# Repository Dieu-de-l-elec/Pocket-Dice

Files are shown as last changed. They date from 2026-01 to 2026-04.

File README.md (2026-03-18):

# Pocket Dice
It's a dice, barely bigger than a coin cell (CR2016), based upon the ATtiny1616, with 7 orange 0603 LEDs . With the press duration being recorded, it should display a near truly random generated number, unlike pseudo random number generator algorithms.

This pocket-sized dice will be my everyday companions for tabletop games or any 6D dice requiring game.

<br><br>
<p align="center">
  RENDER 1 Banner
  PCB Banner
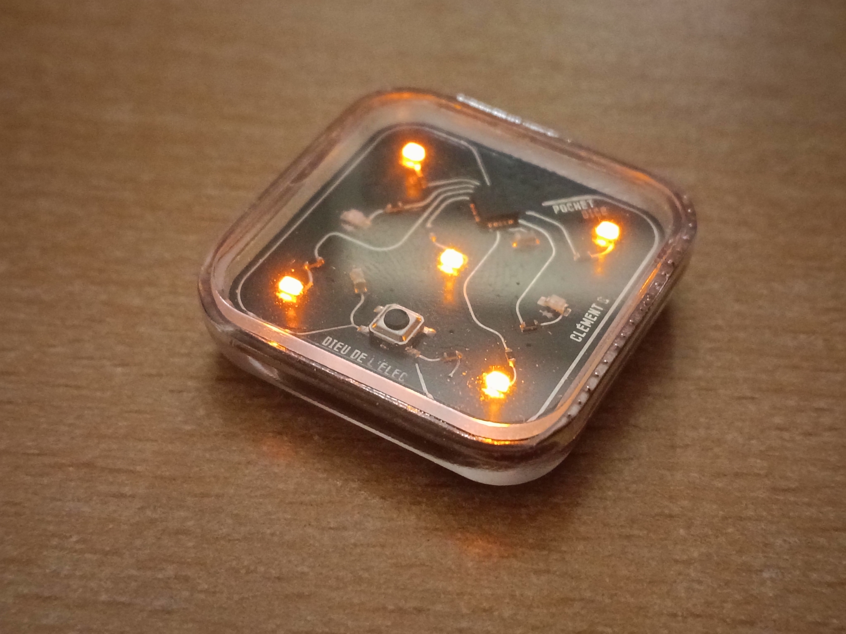
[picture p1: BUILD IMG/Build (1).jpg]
Build Image
  
</p>
<br><br>

# Key features:
- 7x 0603 LEDs (orange LEDs)
- extremely **low power consumption** (2mA average while displaying) ⇒ long battery life (CR2016), but dimmer LEDs... yet still visible enough indoor
- **Attiny1616** MCU: 16Kb Flash, Power Down sleep, extraordinarily low current consumption (VDD = 3V: 300µA running @1MHz, and 100nA in PWR down mode)
- based on **Xoshiro128+** TRNG algorithm
- button **press duration recorded** ⇒ entropy source for TRNG (along with `micros()` and analog noise on floating pin)
- Sleek design: 7mm thick, 30mm by 30mm
- 3d printed enclosure: I used JLC3DP 3D printing service, with Nylon PA12 (MJF) and 8001 transparent resin (SLA), to get a premium case, but it works too with an FDM printer.
- 1mm acrylic sheet on top that can be pressed on the lower half (a bit of flex) to press the button underneath
- MCU programmable via **UPDI**

A demo can be found here:
https://youtu.be/6FqC9Gx21-w

# Sofware:
Arduino code using SpenceKonde **MegaTinyCore** and **Xoshiro128+** TRNG algorithm.

Pressing and holding the button rolls the dice, and once released, settle down to the randomly generated number after another 3 rolls slowing down, to add a bit of animation. The dice outcome stays displayed for another 4 seconds, and then the dice goes into Power Down mode. If we want the previous outcome to be displayed again, the button can be shortly pressed, which will make the dice display the previous outcome with a blinking animation, to ensure it can't be misinterpreted as another roll.

# PCB design:
2 Layer PCB designed in EASYEDA (Pro edition). 26 by 26mm square, panelized in a 3 by 3 panel. 0.8mm board thickness

# Schematic:
SCHEMATIC

# PCB Layout:

PCB Top Layer
PCB PANEL Layout
PCB PANEL back Layout
PCB PANEL 2D
PCB PANEL 2D back

PCB 3 back 3d

# CAD and Renders:

PCB 3d render 1
PCB 3d render 2
PCB 3d render 3

RENDER 1
RENDER 2
RENDER 3
RENDER 4
RENDER 6
RENDER 5

# Build Images:

The top acrylic plate can be glued to the case with a few small drops of cyanoacrylate on the side. It would only be glued to the case along the upper edge, and on the upper half of the sides, to let the plate flex when pressed.

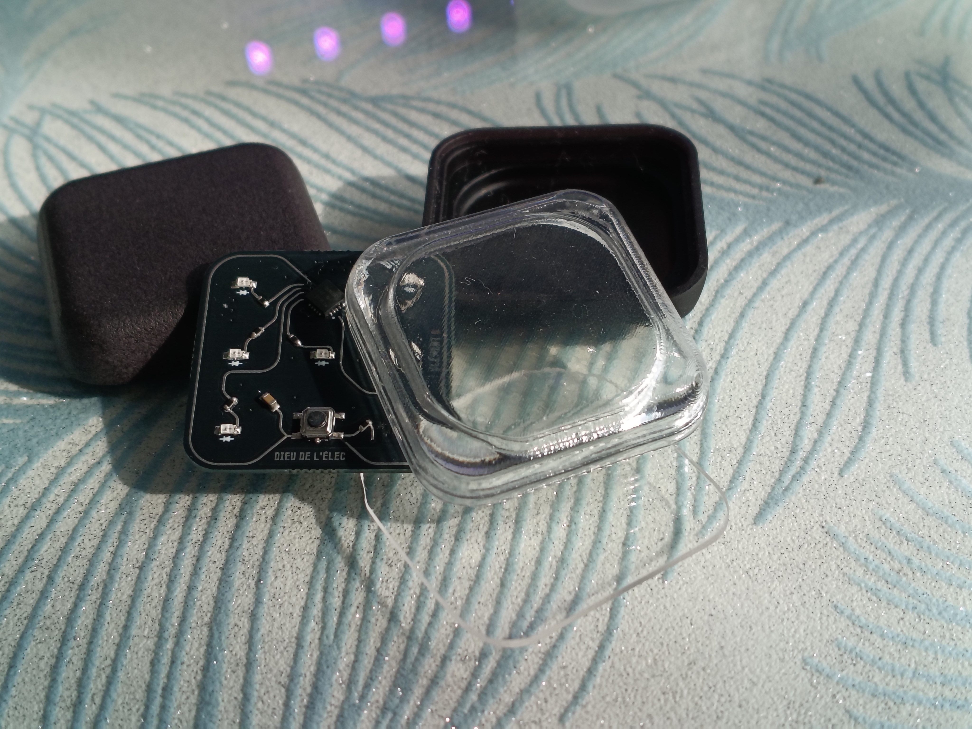
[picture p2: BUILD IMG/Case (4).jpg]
Case dissasembled dice

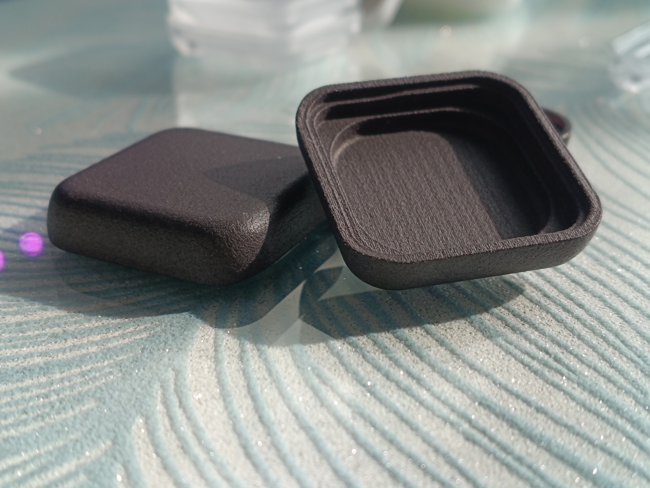
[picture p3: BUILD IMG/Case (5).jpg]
Nylon PA12 MJF case


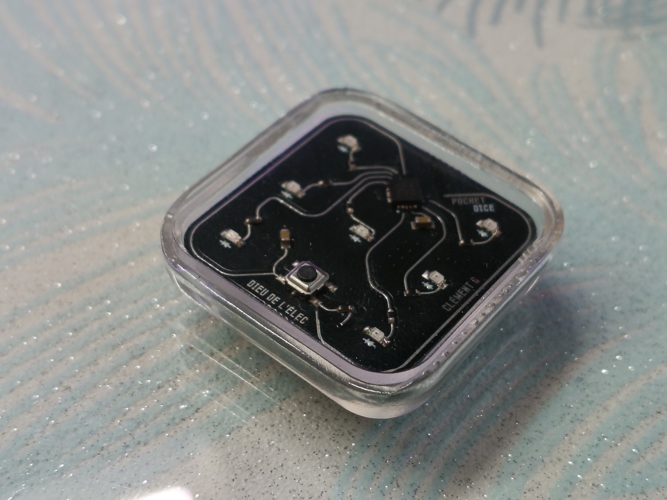
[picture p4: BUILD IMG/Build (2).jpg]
Build Image 2

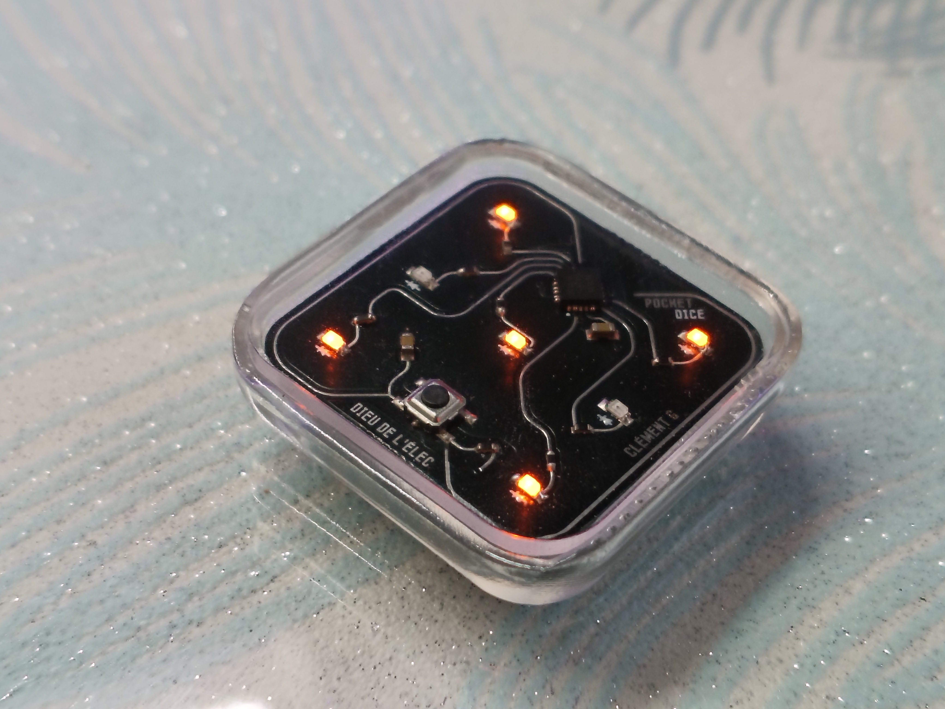
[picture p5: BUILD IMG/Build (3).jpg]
Build Image 3

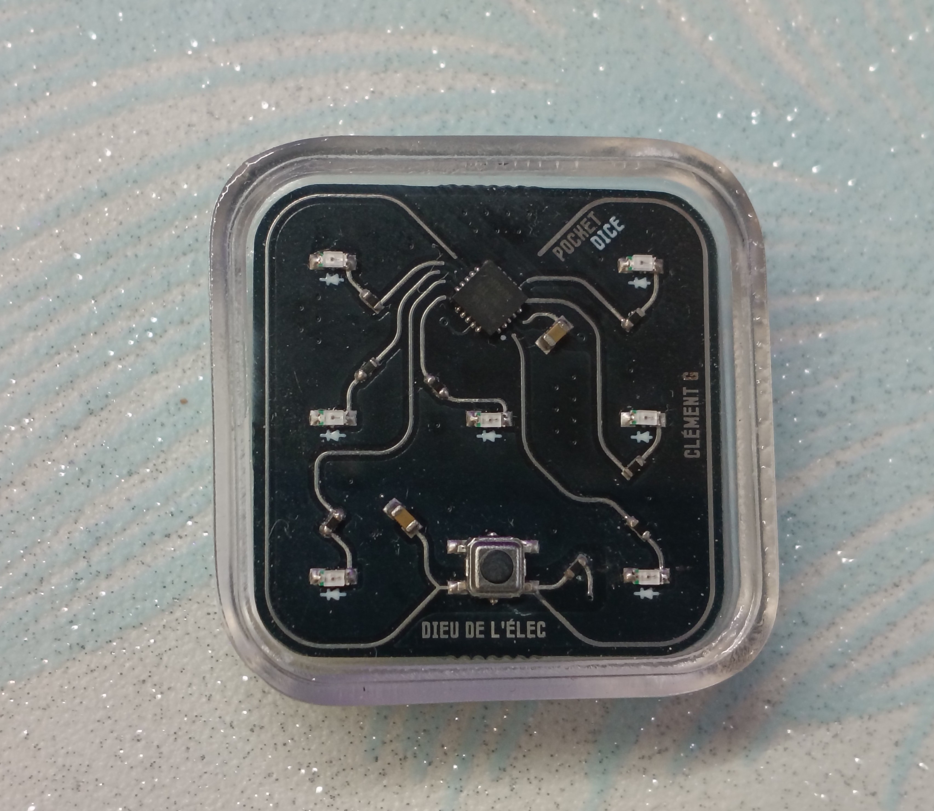
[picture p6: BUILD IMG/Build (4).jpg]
Build Image 4

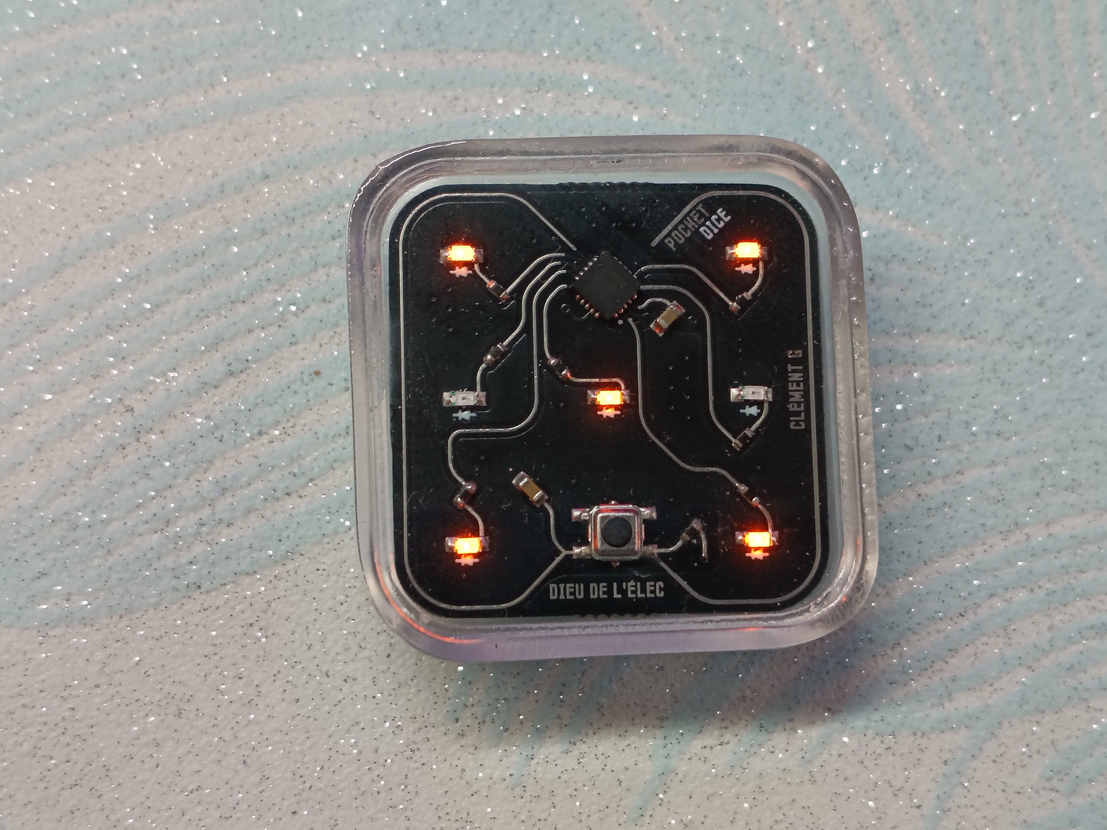
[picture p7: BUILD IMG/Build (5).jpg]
Build Image 5

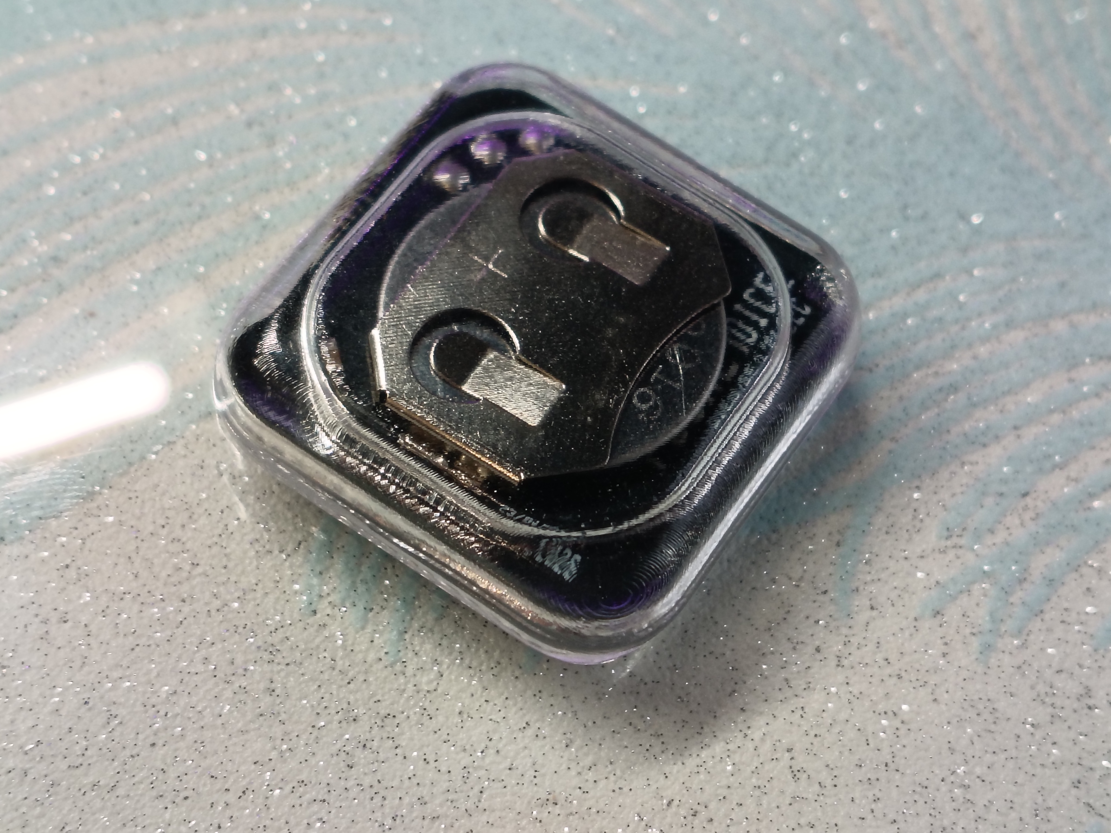
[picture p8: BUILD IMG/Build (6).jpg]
Build Image 6

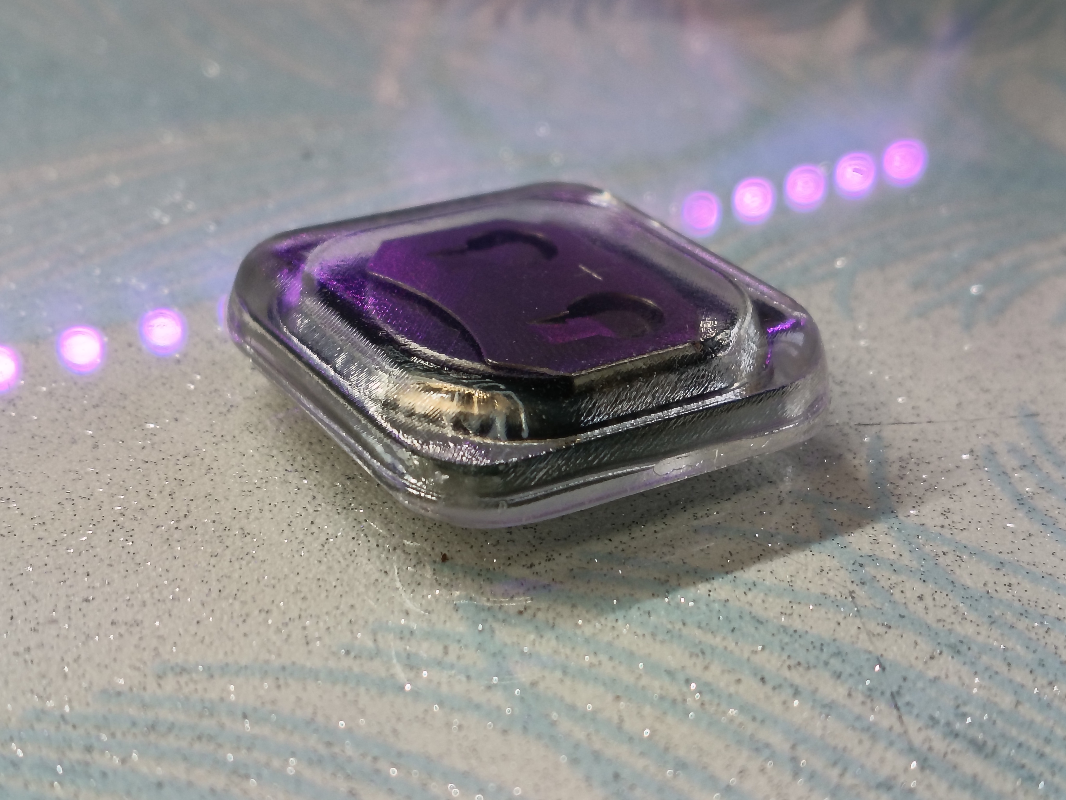
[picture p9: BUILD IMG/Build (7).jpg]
Build Image 7

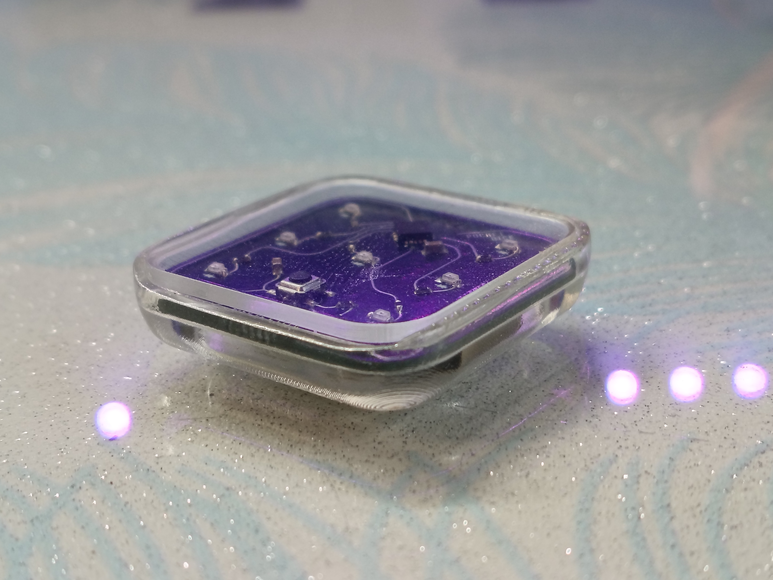
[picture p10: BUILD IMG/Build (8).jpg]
Build Image 8


Build Image 1

# BOM:

Qty	| Part	| Value | link
--- | --- | --- | ---
1 | ATtiny1616-MNR | | https://www.lcsc.com/product-detail/C507118.html
1 | CR2016 Cell SMD metal holder | | https://www.lcsc.com/product-detail/C2979176.html
1 | MLCC 0805 | 10µF | https://www.lcsc.com/product-detail/C1713.html
1 | Tactile Switch TS-1075S-A1B2-D4 | | https://www.lcsc.com/product-detail/C492872.html
2 | MLCC 0603 | 100nF | https://www.lcsc.com/product-detail/C66501.html
1 | Resistor 0402| 200k | https://www.lcsc.com/product-detail/C2906866.html
7 | Resistor 0402| 1k | https://www.lcsc.com/product-detail/C2906864.html
7 | Orange LED 0603 XL-1608UOC-06 | Vf=2.3V | https://www.lcsc.com/product-detail/C965800.html
1	| Custom PCB | | I used JLCPCB services https://jlcpcb.com
--- |  |  | 
1 | 1mm thin transparent acrylic sheet | |	I used Snijlab laser cutting services https://snijlab.nl/en
1 | 3D printed case | MJF - PA12S-HP Nylon or SLA - 8001 transparent resin (oil sprayed) | 	I used JLC3DP3D printing services https://jlc3dp.com/3d-printing-quote
1 | CR2016 Coin Cell | | Physical store

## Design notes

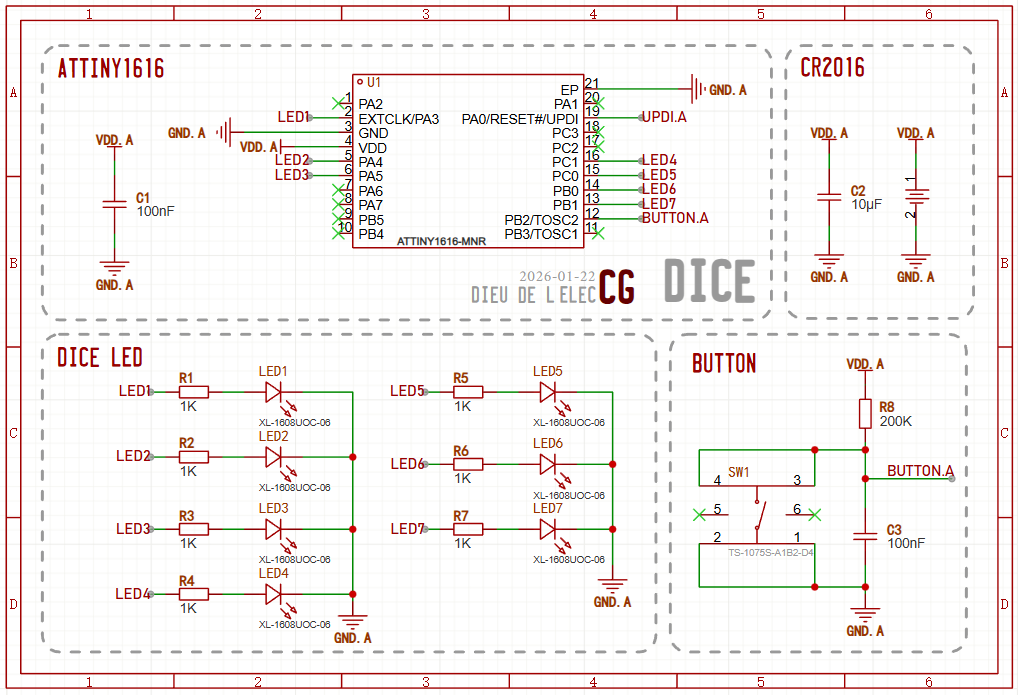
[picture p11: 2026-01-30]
assets/Schematic Dice.png

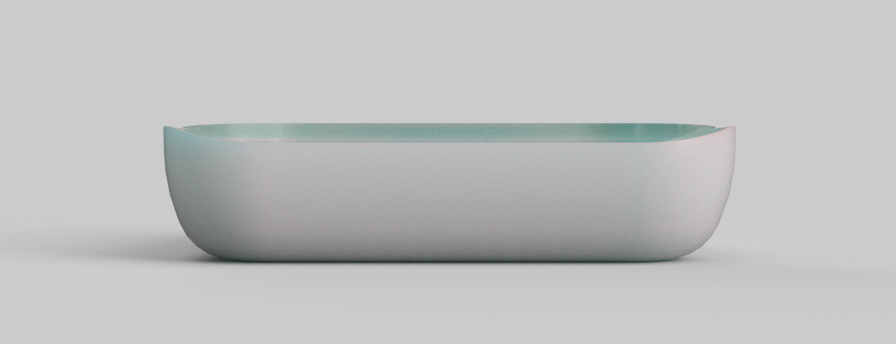
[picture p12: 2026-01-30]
assets/RENDER 3.png

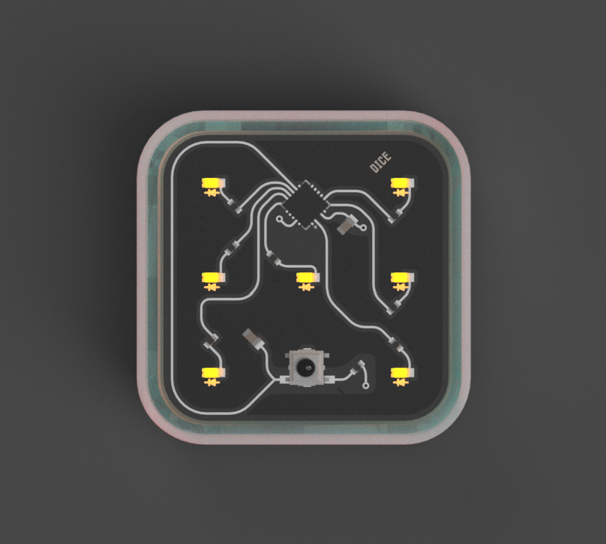
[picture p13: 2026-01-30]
assets/RENDER 2.png

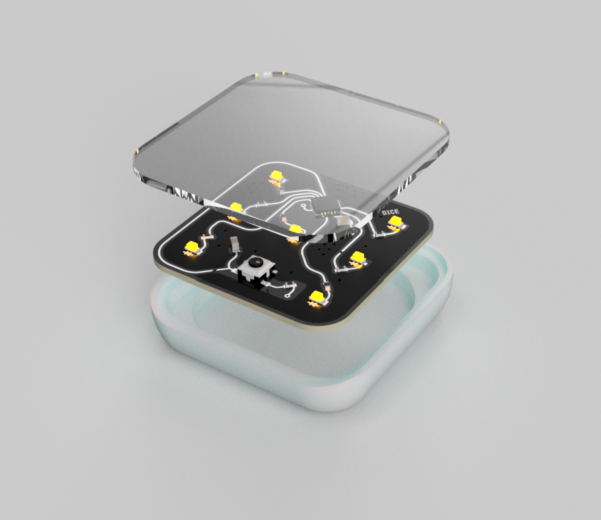
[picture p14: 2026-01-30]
assets/RENDER 5.png

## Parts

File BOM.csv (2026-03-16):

Qty | Part | Value | LCSC Part Number | price jan. 2026 (/MOQ) | Link
1 | ATTINY1616-MNR | - | C507118 | $0.911 (/1) | https://www.lcsc.com/product-detail/C507118.html
1 | metal CR2016 Cell holder | - | C2979176 | $0.76 (/5) | https://www.lcsc.com/product-detail/C2979176.html
1 | MLCC 0805 | 10µF | C1713 | $0.26 (/20) | https://www.lcsc.com/product-detail/C1713.html
1 | Tactile Switch TS-1075S-A1B2-D4 | - | C492872 | $0.6 (/10) | https://www.lcsc.com/product-detail/C492872.html
2 | MLCC 0603 | 100nF | C66501 | $0.35(/100) | https://www.lcsc.com/product-detail/C66501.html
1 | SMD resistor 0402 | 200k | C2906866 | $0.05 (/100) | https://www.lcsc.com/product-detail/C2906866.html
7 | SMD resistor 0402 | 1k | C2906864 | $0.05 (/100) | https://www.lcsc.com/product-detail/C2906864.html
7 | Orange LED XL-1608UOC-06 0603 | Vf=2.3V | C965800 | $0.69 (/100) | https://www.lcsc.com/product-detail/C965800.html
1 | Custom PCB |  |  | $4 | I used JLCPCB services https://jlcpcb.com
 | 1mm thin transparent acrylic sheet |  |  |  | I used Snijlab laser cutting services https://snijlab.nl/en
 | 3d printed case |  |  |  | I used JLC3DP 3D printing services https://jlc3dp.com/3d-printing-quote
 | CR2016 Coin cell |  |  |  | Physical Store

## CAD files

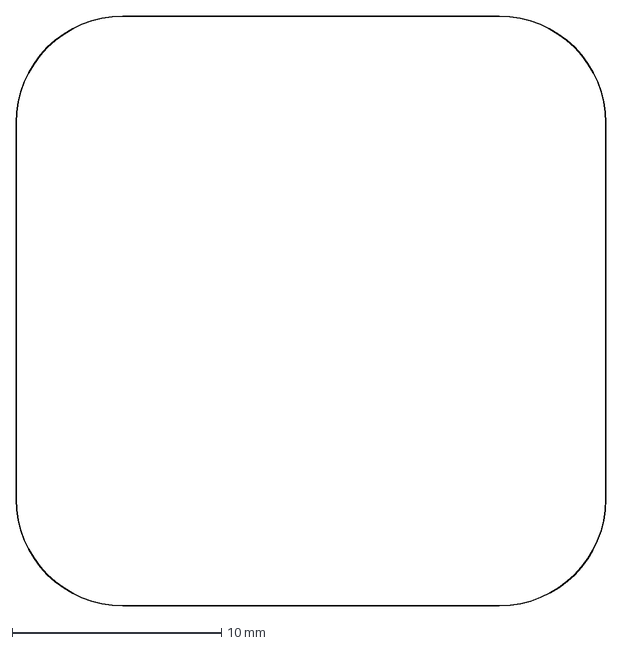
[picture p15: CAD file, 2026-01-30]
CAD/acrylic sheet DXF cutout.dxf
28.2 x 28.2 mm

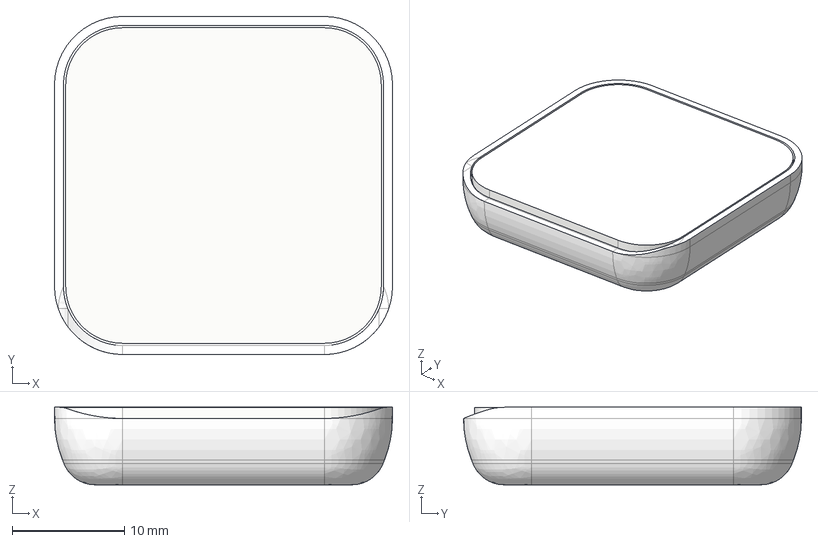
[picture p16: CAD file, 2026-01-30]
CAD/Pocket Dice CAD 3D printed Parts and top acrylic sheet.step
30.2 x 30.2 x 6.93 mm

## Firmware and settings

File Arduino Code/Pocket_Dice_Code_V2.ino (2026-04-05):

/* This is the current code (V2) for the Pocket Dice
 * Dieu de l'Elec - C.G.
 * 03.03.2026
 */ 

#include <avr/sleep.h>
#include <avr/interrupt.h>

#define BUTTON PIN_PB2

unsigned long timeCapture = 0;
volatile unsigned long timeIntCapture = 0;

byte prevDice = 0;
byte outcome = 1;
byte randomOutcome = 1;

//int counterInt = 0; // no longer needed
volatile unsigned long counterIntTime = 0;

// bool stateBtn = false; // no longer needed
volatile bool intAttribute = 1;       // interrupt attribute : 0 => button released (roll), 1 => button pressed (wake up)
// useful to know wether the intterupt means 'button pressed' or 'button released'

uint8_t LEDPins [7] {PIN_PA3, PIN_PA4, PIN_PA5, PIN_PC1, PIN_PB1, PIN_PB0, PIN_PC0};
uint8_t floatingPins [9] {PIN_PA2, PIN_PA6, PIN_PA7, PIN_PB5, PIN_PB4, PIN_PA1, PIN_PC3, PIN_PC2, PIN_PB3};
bool stateLED [7] {0, 0, 0, 0, 0, 0, 0};

void setup() {
  pinMode(BUTTON, INPUT);

  for (int p = 0; p <= 6; p++) {
    pinMode (LEDPins[p], OUTPUT);
  }

  sei();
  PORTB.PIN2CTRL = PORT_ISC_RISING_gc;
  set_sleep_mode(SLEEP_MODE_PWR_DOWN);
  timeCapture = millis();
}

void loop() {
  PORTB.PIN2CTRL = PORT_ISC_RISING_gc;

  if (intAttribute == 1) {             //                   // MCU woke up, but the button is still pressed
    randomOutcome = random(1, 7);      //                   // generate a dice outcome (rolling the dice)
    while (outcome == randomOutcome) { //                   // generate another one if it's the same outcome (just like a real dice that keeps rolling)
      randomOutcome = random(1, 7);    //
    }                                  //
    outcome = randomOutcome;           // just randomly rolling the dice for fun while the button hasn't been released
    displayDice(outcome);              //
    refreshDisplay (120);              //

    if (digitalRead (BUTTON) == 0) {
      counterIntTime = 0;
    }

    if ((millis () - counterIntTime >= 500) & (counterIntTime != 0)) {
      intAttribute = 0;
    }

  }
  if (intAttribute == 0) {                                   // if interrupt has been flagged (button released)
    PORTB.PIN2CTRL = PORT_ISC_INTDISABLE_gc;                 // disabling interrupts so it don't disturb

    unsigned long bufferTimeCapture = timeIntCapture;
    unsigned long duration = millis () - bufferTimeCapture; //bufferTimeCapture - timeCapture;
    //timeCapture = timeIntCapture;
    if (duration <= 800) {             // if short press => display previous outcome
      displayPrev();
      MCUSleep();
      return;
    }
    else {
      prevDice = generateOutcome(duration, micros());
      
      randomOutcome = random(1, 7);      //                   // generate a dice outcome (rolling the dice)
      while (outcome == randomOutcome) { //                   // generate another one if it's the same outcome (just like a real dice that keeps rolling)
        randomOutcome = random(1, 7);    //         Just dummy rolls to look more like a dice, slowing down
      }                                  //
      outcome = randomOutcome;           // just randomly rolling the dice for fun while the button hasn't been released
      displayDice(outcome);              //
      refreshDisplay (260);              //

      randomOutcome = random(1, 7);      //                   // generate a dice outcome (rolling the dice)
      while (outcome == randomOutcome) { //                   // generate another one if it's the same outcome (just like a real dice that keeps rolling)
        randomOutcome = random(1, 7);    //
      }                                  //
      outcome = randomOutcome;           // just randomly rolling the dice for fun while the button hasn't been released
      displayDice(outcome);              //
      refreshDisplay (400);              //         Just dummy rolls to look more like a dice, slowing down

      displayDiceOutcome(prevDice);
      MCUSleep();
      return;
    }
  }
}

void MCUSleep()  {
  PORTB.PIN2CTRL = PORT_ISC_INTDISABLE_gc;                 // disabling interrupts so it don't disturb
  for (int p = 0; p <= 6; p++) {          // LED GPIOs OFF
    digitalWrite (LEDPins[p], LOW);
  }
  for (int p = 0; p <= 8; p++) {
    pinMode (floatingPins[p], OUTPUT); 
  }

  ADC0.CTRLA &= ~ADC_ENABLE_bm;
  PORTA.PIN2CTRL = PORT_ISC_INTDISABLE_gc; //{PIN_PA2, PIN_PA6, PIN_PA7, PIN_PB5, PIN_PB4, PIN_PA1, PIN_PC3, PIN_PC2, PIN_PB3};
  PORTA.PIN6CTRL = PORT_ISC_INTDISABLE_gc;
  PORTA.PIN7CTRL = PORT_ISC_INTDISABLE_gc;
  PORTB.PIN5CTRL = PORT_ISC_INTDISABLE_gc;
  PORTB.PIN4CTRL = PORT_ISC_INTDISABLE_gc;
  PORTA.PIN1CTRL = PORT_ISC_INTDISABLE_gc;
  PORTC.PIN3CTRL = PORT_ISC_INTDISABLE_gc;
  PORTC.PIN2CTRL = PORT_ISC_INTDISABLE_gc;
  PORTB.PIN3CTRL = PORT_ISC_INTDISABLE_gc;

  PORTB.PIN2CTRL = PORT_ISC_FALLING_gc;     // | re-enabling Button interrupt
  PORTB.INTFLAGS = PIN2_bm;                 // |
  sleep_enable();
  sei();
  sleep_cpu();
  for (int p = 0; p <= 6; p++) {          // LED GPIOs OFF
    pinMode (LEDPins[p], OUTPUT);
  }

  ADC0.CTRLA |= ADC_ENABLE_bm;
  sleep_disable();
}

ISR (PORTB_PORT_vect) {
  PORTB.INTFLAGS = PIN2_bm;
  if (digitalRead (BUTTON) == 0) {    // interrupt when button pressed (wake up)
    timeIntCapture = millis();
    intAttribute = 1;
  }
  else {                              // interrupt when button released (roll dice)
    counterIntTime = millis();
  }
}

void displayPrev() {
  for (int i = 0; i < 4; i++) {
    displayDice (prevDice);                     // display previous outcome
    refreshDisplay(600);                        //    for 4 seconds total
    displayDice (0);
    refreshDisplay(400);
  }
}

byte generateOutcome(unsigned long bcSeed, unsigned long prSeed) {
  setSeed(bcSeed, prSeed);
  byte value = roll_die();
  return value;

}

void displayDiceOutcome(byte diceValue) {
  displayDice (diceValue);                    // display outcome
  refreshDisplay(4000);                       //    for 4 seconds
}

void displayDice (int value) {
  switch (value) {
    case 0 :
      stateLED [0] = 0;
      stateLED [1] = 0;
      stateLED [2] = 0;
      stateLED [3] = 0;
      stateLED [4] = 0;
      stateLED [5] = 0;
      stateLED [6] = 0;
      break;
    case 1 :
      stateLED [0] = 0;
      stateLED [1] = 0;
      stateLED [2] = 0;
      stateLED [3] = 1;
      stateLED [4] = 0;
      stateLED [5] = 0;
      stateLED [6] = 0;
      break;
    case 2 :
      stateLED [0] = 0;
      stateLED [1] = 0;
      stateLED [2] = 1;
      stateLED [3] = 0;
      stateLED [4] = 0;
      stateLED [5] = 0;
      stateLED [6] = 1;
      break;
    case 3 :
      stateLED [0] = 0;
      stateLED [1] = 0;
      stateLED [2] = 1;
      stateLED [3] = 1;
      stateLED [4] = 0;
      stateLED [5] = 0;
      stateLED [6] = 1;
      break;
    case 4 :
      stateLED [0] = 1;
      stateLED [1] = 0;
      stateLED [2] = 1;
      stateLED [3] = 0;
      stateLED [4] = 1;
      stateLED [5] = 0;
      stateLED [6] = 1;
      break;
    case 5 :
      stateLED [0] = 1;
      stateLED [1] = 0;
      stateLED [2] = 1;
      stateLED [3] = 1;
      stateLED [4] = 1;
      stateLED [5] = 0;
      stateLED [6] = 1;
      break;
    case 6 :
      stateLED [0] = 1;
      stateLED [1] = 1;
      stateLED [2] = 1;
      stateLED [3] = 0;
      stateLED [4] = 1;
      stateLED [5] = 1;
      stateLED [6] = 1;
      break;
  }
}


void refreshDisplay (unsigned long duration) {
  unsigned long startTime = millis();
  while (millis() - startTime <= duration) {
    digitalWrite (LEDPins [0], stateLED[0]);
    delayMicroseconds (10);
    for (int l = 0; l <= 6; l++) {
      int n = (l + 1) % 7;
      digitalWrite (LEDPins [l], stateLED[l]);
      digitalWrite (LEDPins [n], stateLED[n]);
      delayMicroseconds (10);
      digitalWrite (LEDPins [l], 0);
    }
    digitalWrite (LEDPins [6], 0);
  }
}

/*************** Xoshiro128+ TRNG algorithm ***************/

void setSeed (unsigned long bcSeed, unsigned long prSeed) {
  uint32_t seed = bcSeed ^ micros() ^ prSeed ^ analogRead(2);       // adding entropy: floating analog pin reading, press duration, and micros()
  for (int i = 0; i < 4; i++) {
    seed ^= prSeed << (i * 8);
    seed ^= bcSeed;
  }
  xoshiro_seed(seed);
}

uint32_t s[4];
static inline uint32_t rotl(const uint32_t x, int k) {
  return (x << k) | (x >> (32 - k));
}

uint32_t xoshiro128plus() {
  uint32_t result = s[0] + s[3];
  uint32_t t = s[1] << 9;

  s[2] ^= s[0];
  s[3] ^= s[1];
  s[1] ^= s[2];
  s[0] ^= s[3];

  s[2] ^= t;
  s[3] = rotl(s[3], 11);
  return result;
}

void xoshiro_seed(uint32_t seed) {
  uint64_t z = seed + 0x9E3779B97F4A7C15ULL;
  for (int i = 0; i < 4; i++) {
    z = (z ^ (z >> 30)) * 0xBF58476D1CE4E5B9ULL;
    z = (z ^ (z >> 27)) * 0x94D049BB133111EBULL;
    z = z ^ (z >> 31);
    s[i] = (uint32_t)z;
  }
}

// Roll a fair 1-6 using rejection sampling to avoid bias
int roll_die() {
  uint32_t r;
  do {
    r = xoshiro128plus() & 0xFFFFFFFFUL;  // use full 32 bits
  } while (r >= 0xFFFFFFFFUL - (0xFFFFFFFFUL % 6));
  return (r % 6) + 1;
}

/***************           * * *            ***************/
